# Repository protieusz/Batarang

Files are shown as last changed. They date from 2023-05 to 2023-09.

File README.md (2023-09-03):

# Batarang
Batman theme ~~handwired~~ keeb. KLE remixed by jade the maid and pcb design by yours truly. MCU used is Pimoroni PGA2040.

I accept any tips or donations of a cup of coffee to help keep me motivate but you don't have to if you don't want to. Thanks. https://ko-fi.com/protieusz

Rev 5 Final PCB built with 1 minor issue, traces for D+ and D- for the usb breakout board is routed wrong so I have to do handwiring to fix it. Cirque trackpad holder 3d stl still need work since my own mods did not quite fit so I had to borrow Dilemma's trackpad hold for 40mm diameter size and hot glued it onto the pcb. I might try to create a 3D trackpad holer that fits the pcb.











Cirque integration to the pcb




D+ and D- traces got swapped fix.










Rev 6, fixed mcu outline, added Cirque trackpad outline. Currently being printed and finger crossed. Still need to figure out the Cirque coding.

May 18, 2023 - Uploaded and released Rev 7B for public. Untested, so please print at your own risk. No support is given.

Rev 7B Pcb pics:
Front side


Back side


Front side


Bottom side


Rev 2 pcb design. Might got straight to pcb instead and skip handwiring. Front side. Will use a Cirque Glidepoint Trackpad instead.



Backside


Old Design



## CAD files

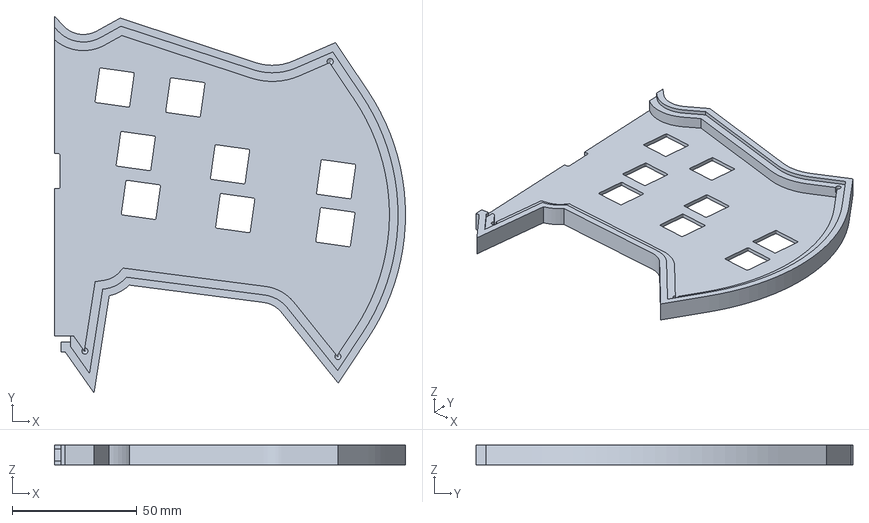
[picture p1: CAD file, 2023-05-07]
Pcboffset 3D files/rpl/BatarangV2LeftCasewPCBoffset.3mf
140.5 x 150.9 x 8.00 mm

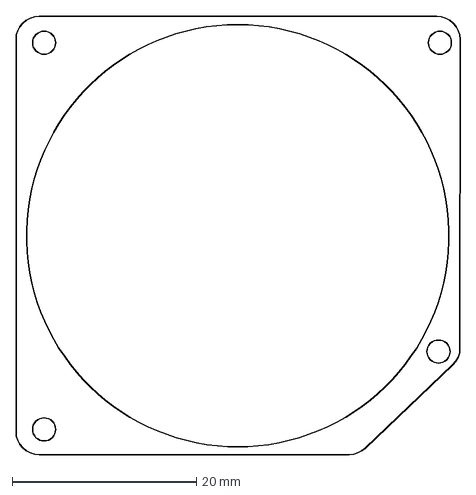
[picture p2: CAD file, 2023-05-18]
Pcboffset 3D files/STLs/ImprovedVersionTBcaseSketch.dxf
48.2 x 47.6 mm

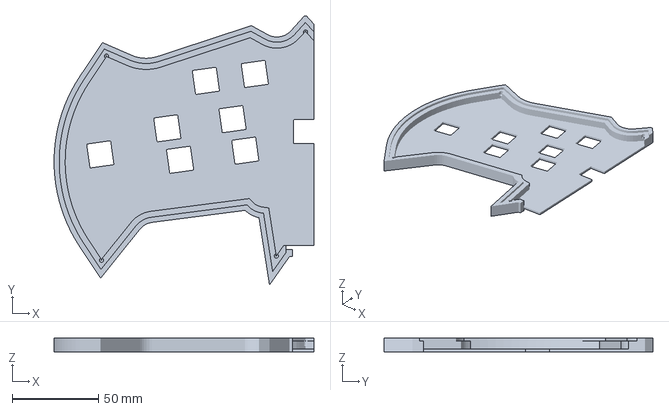
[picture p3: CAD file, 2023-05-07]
Pcboffset 3D files/rpl/BatarangV2RightCasewPCBoffset.3mf
150.3 x 155.6 x 8.00 mm

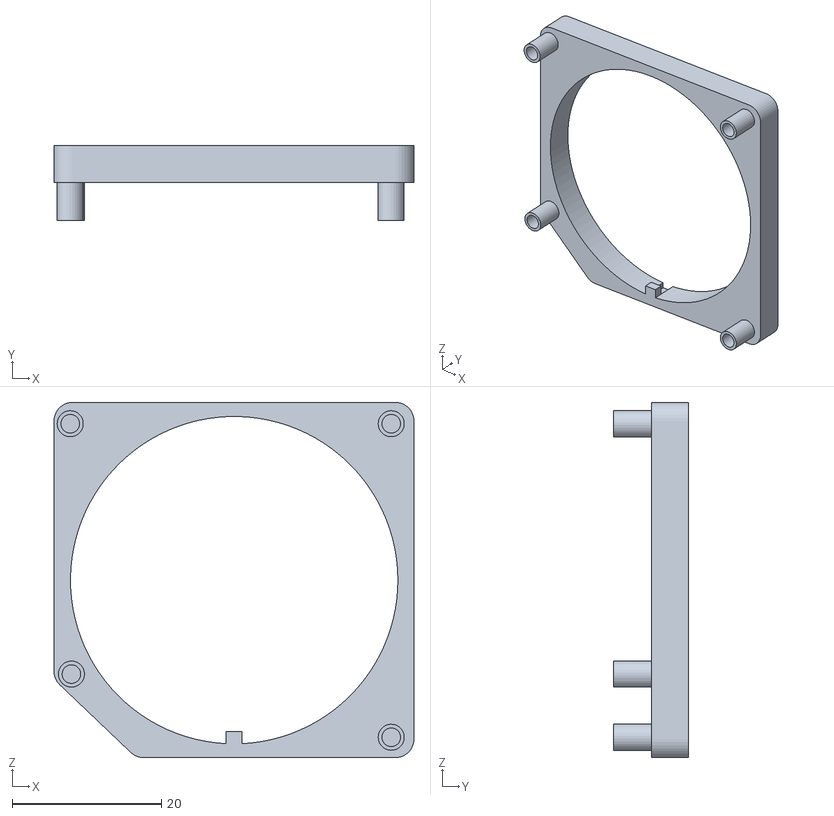
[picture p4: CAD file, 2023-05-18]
Pcboffset 3D files/STLs/BatarangCirqueTBCaseRev7bImproved.stl
48.2 x 10.0 x 47.6

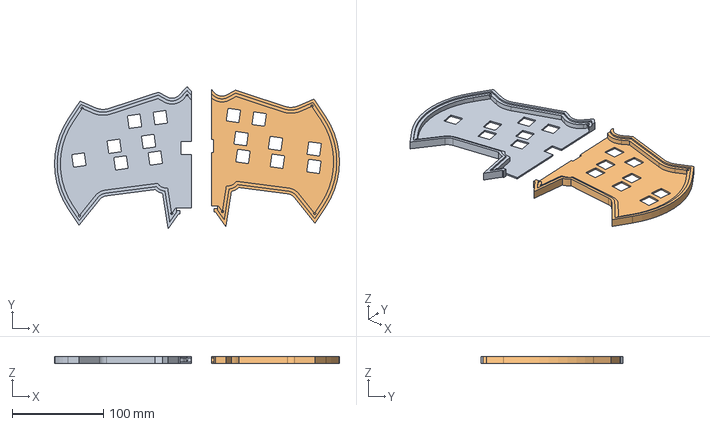
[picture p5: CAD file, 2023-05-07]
Pcboffset 3D files/STLs/BatarangV2PGACase.step
312.7 x 155.6 x 8.00 mm

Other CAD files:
Pcboffset 3D files/STLs/BatarangV2LeftCasewPCBoffset.stl
Pcboffset 3D files/STLs/BatarangV2RightCasewPCBoffset.stl

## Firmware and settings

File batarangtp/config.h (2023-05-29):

/*
 * Copyright 2021 Quentin LEBASTARD <qlebastard@gmail.com>
 * Copyright 2022 Charly Delay <charly@codesink.dev> (@0xcharly)
 *
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
 * You should have received a copy of the GNU General Public License
 * along with this program.  If not, see <http://www.gnu.org/licenses/>.
 */

#pragma once

//#define RP2040_BOOTLOADER_DOUBLE_TAP_RESET // Activates the double-tap behavior
//#define RP2040_BOOTLOADER_DOUBLE_TAP_RESET_TIMEOUT 200U // Timeout window in ms in which the double tap can occur.

#ifdef COMBO_ENABLE
//#    define COMBO_COUNT 6
#    define COMBO_TERM 200
#endif

/* Pointing device configuration. */

// Limits the frequency that the sensor is polled for motion.
#define POINTING_DEVICE_TASK_THROTTLE_MS 10

// Adjust trackpad rotation.
#define POINTING_DEVICE_ROTATION_90

// Configure for the Cirque model used on the Dilemma.
#define CIRQUE_PINNACLE_DIAMETER_MM 40
#define CIRQUE_PINNACLE_CURVED_OVERLAY
#define POINTING_DEVICE_GESTURES_SCROLL_ENABLE // Circular scroll. in this mode enables circular scroll. Touch originating in outer ring can trigger scroll by moving along the perimeter. Near side triggers vertical scroll and far side triggers horizontal scroll.
#define CIRQUE_PINNACLE_ATTENUATION EXTREG__TRACK_ADCCONFIG__ADC_ATTENUATE_3X


//Drasha settings
#define CIRQUE_PINNACLE_TAP_ENABLE //Enable tap to "left click".
//#define POINTING_DEVICE_GESTURES_CURSOR_GLIDE_ENABLE

//#define CIRQUE_PINNACLE_SECONDARY_TAP_ENABLE //Tap in upper right corner (half of the finger needs to be outside of the trackpad) of the trackpad will result in "right click".

/* Cirque trackpad. */
#define SPI_SCK_PIN GP18
#define SPI_MOSI_PIN GP19
#define SPI_MISO_PIN GP16
#define POINTING_DEVICE_CS_PIN GP17

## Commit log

2023-05-07 3D case for Batarang pcb
    [BatarangV2LeftCasewPCBoffset.3mf, BatarangV2LeftCasewPCBoffset.stl, BatarangV2PGACase.step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]
2023-05-18 Add gerber files Rev 7B
2023-05-18 Add trackpad case holder for Rev 7B pcb
    [BatarangCirqueTBCaseRev7bImproved.stl, ImprovedVersionTBcaseSketch.dxf]
2023-05-18 Add Rev 7B pcb pics
2023-05-27 Update config.h
    Update attenuate and invert to 90 degree
    [config.h]
2023-05-27 Update config.h
    Invert 90 degree
    [config.h]
2023-05-27 Update info.json
    Enable encoder
2023-05-27 Update keymap.c
    Correct encoder vold volu orientation, add directional keys, mouse buttons and positioned the space and backspace better.

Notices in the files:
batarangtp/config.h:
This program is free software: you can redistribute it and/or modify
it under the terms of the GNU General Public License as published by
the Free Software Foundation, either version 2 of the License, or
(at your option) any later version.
